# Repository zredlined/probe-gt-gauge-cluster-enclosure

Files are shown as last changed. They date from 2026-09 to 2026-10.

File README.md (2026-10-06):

# Probe GT gauge cluster enclosure

A 3D-printed housing and roll-cage mount for the stock 1993 Ford Probe GT gauge cluster in our 24 Hours of Lemons car.
The dash is gone; the cluster lives in a two-piece charcoal ASA shell with a sun brow, bolted through its own OEM
mounting holes to two small printed feet and two bosses in the roof, and the shell hangs off the dash crossbar and the
two steering-support tubes on four split clamps. Designed from a 3D scan of the cluster and of the cage.

| | | |
|---|---|---|
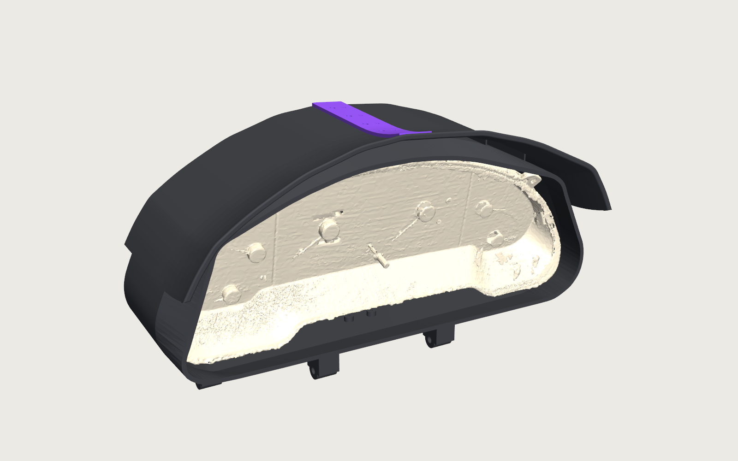
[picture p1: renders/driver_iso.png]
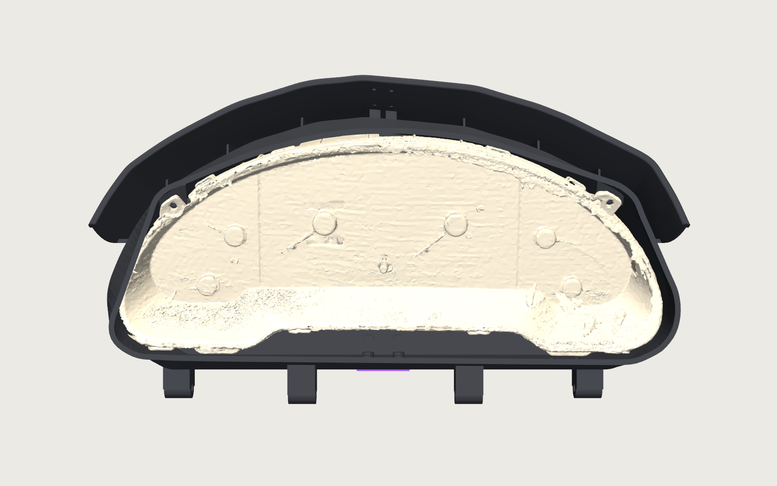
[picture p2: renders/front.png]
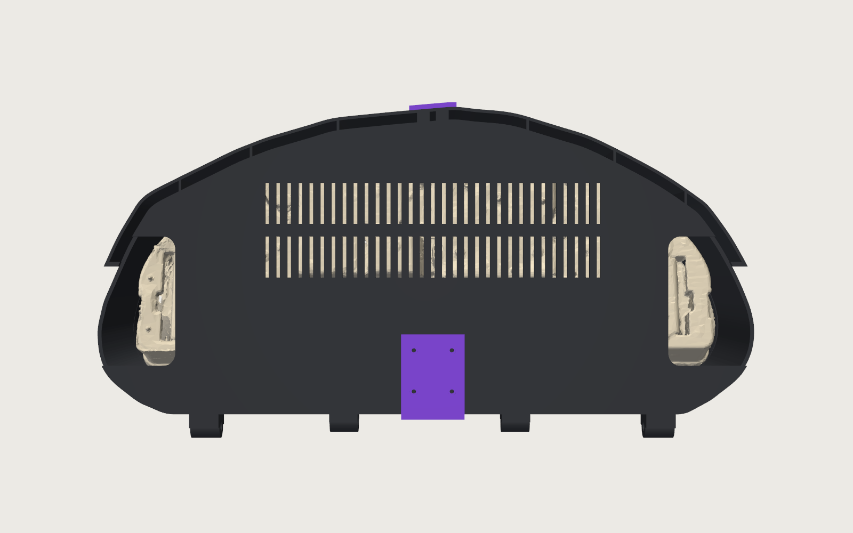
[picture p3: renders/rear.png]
|  |  |  |
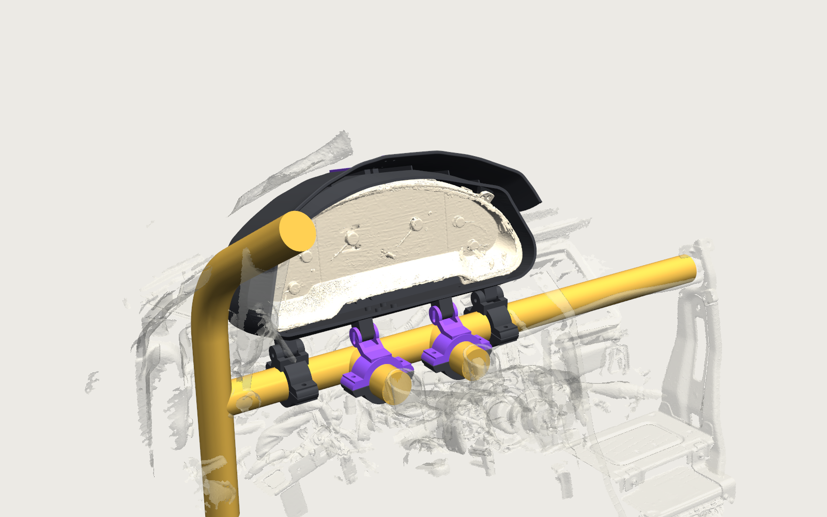
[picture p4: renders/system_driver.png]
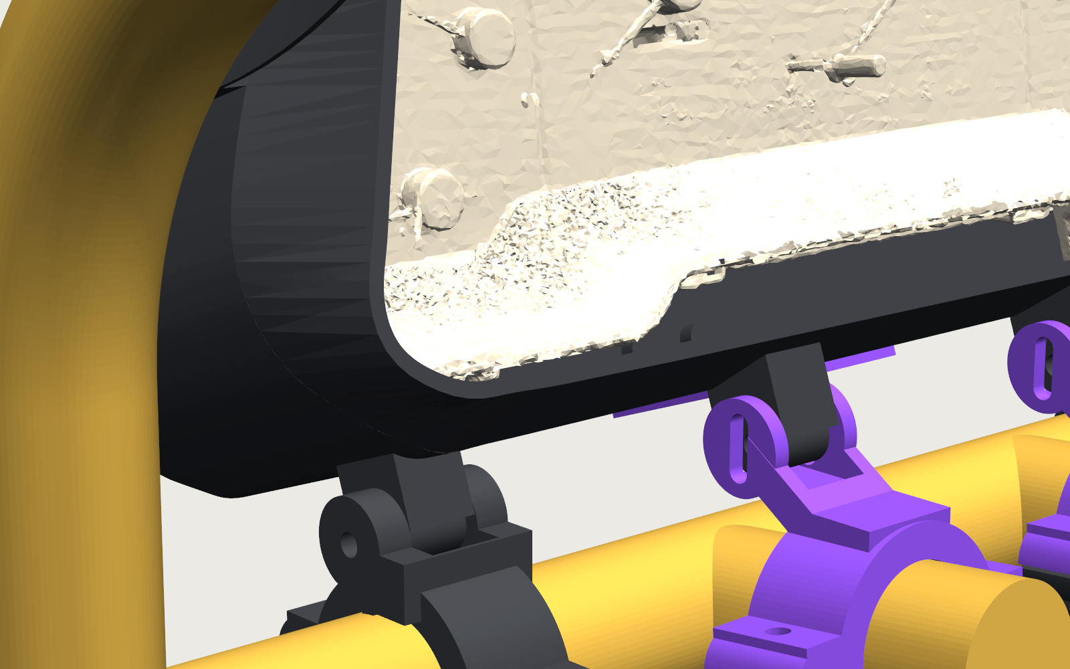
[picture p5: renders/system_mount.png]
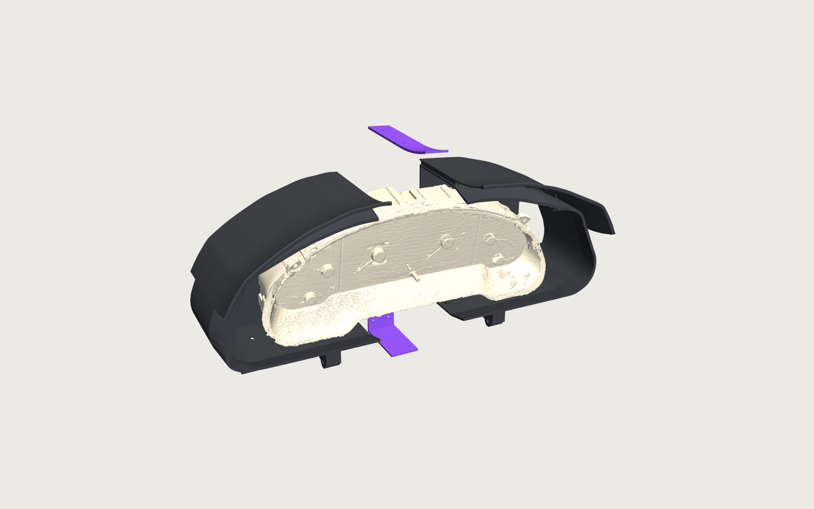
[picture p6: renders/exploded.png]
|  |  |  |

## Print

All files in [`stl/`](stl/) are already oriented for the bed (Bambu P1S, 256 mm). ASA, 0.2 mm layers, 4 walls. The shells
take about 11 hours each; every other part is under 1.5 hours.

| Part | File | Qty | Colour | g | Infill | Supports |
|---|---|---|---|---|---|---|
| Shell L | [shell_L.stl](stl/shell_L.stl) | 1 | charcoal | 396 | 30 % gyroid | tree, only under the two knuckles; brim |
| Shell R | [shell_R.stl](stl/shell_R.stl) | 1 | charcoal | 379 | 30 % gyroid | same |
| Spine bar | [spine_bar.stl](stl/spine_bar.stl) | 1 | purple | 18 | 100 % | small support under the brow tip |
| Keel bar | [keel_bar.stl](stl/keel_bar.stl) | 1 | purple | 16 | 100 % | none |
| Foot L, Foot R | [foot_L.stl](stl/foot_L.stl), [foot_R.stl](stl/foot_R.stl) | 1 each | charcoal | 11 | 60 % | none |
| Bar clamp upper, driver and center | [driver](stl/bar_clamp_upper_driver.stl), [center](stl/bar_clamp_upper_center.stl) | 1 each | charcoal | 41 | 60 % | none |
| Bar clamp lower, driver and center | [driver](stl/bar_clamp_lower_driver.stl), [center](stl/bar_clamp_lower_center.stl) | 1 each | charcoal | 34 | 60 % | none |
| Arm clamp upper, driver and center | [driver](stl/arm_clamp_upper_driver.stl), [center](stl/arm_clamp_upper_center.stl) | 1 each | purple | 44 | 60 % | small support under the strut |
| Arm clamp lower, driver and center | [driver](stl/arm_clamp_lower_driver.stl), [center](stl/arm_clamp_lower_center.stl) | 1 each | charcoal | 34 | 60 % | none |

About 1.2 kg total. Looking at the gauges, L parts go on the right-hand side (the lug plate with round holes) and R
parts on the left (the plate with the slotted hole); every bracket is marked with 1 dot for L, 2 for R. `stl/test/` holds
optional fit aids: ear-boss coupons and ±3° foot variants.

Polymaker ASA on the P1S: nozzle 255 (260 first layer), bed 100 then 95, part fan 15 %, aux fan off, door closed, chamber
preheated, dry the spool first.

## Hardware

Nuts are plain M4 (7.0 AF, 3.2 thick) unless marked nyloc. No heat-set inserts.

| Item | Qty | Where |
|---|---|---|
| M4 x 16 + nut + washer (9 mm OD max) | 4 | lug plates to the feet |
| M4 x 20 + nut + washer | 2 | ear tabs to the roof bosses, from the front through the notch in the lens |
| M4 x 10 + nut | 4 | shell to feet, from below |
| M2.5 x 8 | 18 | spine bar (6) and keel bar (8) self-tapped into printed pilots, brow (4) with M2.5 nuts and washers |
| M6 x 55 + nyloc + 2 washers | 4 | pivot and lock pins through the clamp clevises |
| M6 x 40 + nyloc + washer | 8 | the four split clamps |

Shopping list: 10 M4 nuts, 6 M4 washers, 4 M2.5 nuts and washers, 12 M6 nylocs, 16 M6 washers, plus the bolts above.

## Assembly

1. Press M4 nuts into the hex pockets on the back of each foot slab and into the rear slots of each foot pad.
2. Cluster face down. Foot L behind the face-right lug plate, Foot R behind the face-left plate. Four M4 x 16 from the front.
3. Shell L on its outer side. Drop an M4 nut into the ear-boss channel (it opens upward in this position). Lower the
   cluster with its feet in from the split plane: pads on the bottom wall over the slots, ear tab against the boss.
4. Nut into Shell R's boss channel, then close Shell R over the cluster.
5. Two M4 x 20 from the front through the lens notches into the ear bosses. Four M4 x 10 from below into the feet; slide
   the cluster on the slots until the lens sits about 3 mm behind the nose rim, then tighten.
6. Spine bar: six M2.5 into the roof pilots, four through the brow with nuts. Keel bar: eight M2.5. Hand driver, stop at seat.
7. Ribbon cables in through the rear-corner ports, thumb locks outboard.
8. In the car: bar clamps loose at 107 and 417 mm from the driver-upright weld, clevises up; arm clamps loose about 55 mm
   forward along each steering-support tube, struts up and leaning back.
9. Drop the pivot knuckles into the bar-clamp clevises and the lock knuckles into the arm-clamp slots; four M6 x 55,
   heads outboard. Sit in the seat, set the pitch, tighten pivots, locks, arm clamps, bar clamps. On the bar clamps put
   the bolt heads underneath and the nylocs on top: the cowl-side nuts sit 33 mm under the shell, enough for an open-end
   wrench but not a ratchet.

To remove the cluster: four M6, lift off, two M4 from the front, four M4 from below, bars off, halves apart.

## Design

- The cluster is held only through its OEM holes: four M4 into nuts captured in the feet, two M4 into nuts in bosses
  moulded into the roof. Nothing is glued or drilled.
- The shell's front is a nose lofted to the scanned outline of the bezel rim with 2.5 mm clearance; the roof is a double
  skin over a ventilated air gap that continues as a 70 mm brow. The back is closed with two rows of vents and a port at
  each corner for the ribbon plugs.
- Four identical M6 knuckles on the bottom wall: two pivots directly above the crossbar, two pitch locks 33 mm forward
  above the steering-support tubes, locked on slots.
- Every fastener is driven from outside or on the bench. The generator checks driver reach for all 52 fasteners and
  samples every part against every other part and the cage; the current state is in
  [renders/inspection_sheet.png](renders/inspection_sheet.png).

CAD: Onshape document [937c54b34f0ccb974f37f949](https://cad.onshape.com/documents/937c54b34f0ccb974f37f949) (assembly ids
in `cad/output/onshape_ids.json`). Engineering details: [docs/engineering-notes.md](docs/engineering-notes.md).

## Regenerate

Everything is generated from constants in `cad/generate.py` (shell, feet; scan frame) and `cad/mount.py` (placement,
clamps; car frame). `cad/build.sh` runs the pipeline: geometry, placement, fastener and interference checks, bed-oriented
STLs into `stl/`, renders into `renders/`. `cad/push.py` uploads the FeatureScript to Onshape and rebuilds both
assemblies (about 30 API requests). Environment, once:

```bash
uv venv cad/.venv && uv pip install --python cad/.venv/bin/python cadquery trimesh shapely scipy ezdxf pyvista requests rtree networkx
```

```
cad/         generator, checks, print prep, renders, Onshape push; cad/output holds the generated FeatureScript
stl/         printable files (bed-oriented); stl/test for fit aids
renders/
reference/   cluster_scan (mesh, silhouettes, hole CSV) and cage_scan (fitted tubes, surroundings)
docs/        engineering notes
```

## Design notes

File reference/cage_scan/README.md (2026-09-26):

# Probe cage and dash reference — revision 2

Start with **ONSHAPE_AGENT_HANDOFF.md**. Import **cage_and_dash_reference_mm.stl** in **millimeters**. For separate cage/context visibility, use **cage_primary_tubes_mm.stl** plus **dash_surroundings_mm.stl** instead. All car-reference meshes share coordinates.

The fitted cage is the 1.75-inch (44.45 mm) dash crossbar, driver front upright/bend, and **both tubes reaching toward the steering column**. The arms are also available separately as `cage_steering_support_tubes_mm.stl`; see `steering_support_detail_reference.png`. Their terminal fittings remain scanned surfaces. Gray context preserves the scanned switch, steering hardware and surrounding dash/cowl. The gold color in the PLY and previews is assigned for identification; this scan contains no usable color.

The user's intent is to retain the gauge cluster near its OEM position behind the steering wheel, lift it above the position in the photo, and mount the enclosure at multiple separated front-cage points. Driver eye position remains adjustable.

This is an incomplete spatial reference, not a printable combined solid or a finished mount. Wheel, cluster and full windshield opening are absent from the car scan. The separate earlier cluster reference is in its own coordinates and has not been placed in the car.

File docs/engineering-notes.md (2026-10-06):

# Engineering notes

The non-obvious facts you need to change the design without re-learning them on the printer.

## Frames

- **Scan frame** (enclosure, feet, `cad/generate.py`): X across the cluster, **Y down in the car**, Z toward the driver.
  Scan +X is the driver's left. Part names L / R follow the scan: **L is the face-right side** of the cluster (round-hole
  lug plate, scan holes B2 B3 T1), **R is the face-left side** (slotted lug hole, B5 B6 T2). Every bracket carries dots:
  1 = L, 2 = R.
- **Car frame** (mount, `cad/mount.py`): X along the dash crossbar driver to passenger, Y toward the cowl, Z up, origin on
  the crossbar axis at the driver upright. Scan to car is `car = (X_C - x, -z, -y)` then a 20 deg pitch about X; the
  front-bottom edge of the shell lands `FACE_Y` behind the bar and `EDGE_LIFT` above it.

## What the scan got wrong (calipers, 2026-09-27 to 10-02)

- Mounting holes are all 5.3 mm (B6 is a 5.3 x 8.8 slot); the scan said 5.3 to 6.8. Hole pair spacing 19.7, not 20.2.
- The CSV hole centres lie on the tabs' rear faces. Lug plates 4.8 thick, ear tabs 7.0 thick, 19.5 wide, 10 tall, hole
  5 below the tip; the lens is notched around each tab. Each lug plate has a rib on its outer edge 6 to 7 mm outboard of
  the outer hole.
- The scanner did not see the clear lens: it stands 11 mm proud of the scanned rim and 5 mm proud of the black frame.
- The cluster is 2 to 3 mm deeper than the scan at the rear.
- The bezel shroud tapers toward the face (scanned top edge y -81.6 at the back, -70 at the rim). An opening drawn to the
  widest outline leaves 17 to 29 mm of air; the nose is lofted to the hull of scan vertices with z >= 36 instead.
- Ribbon plugs are 51 and 59.8 x 9.6 mm with a 4 mm thumb lock outboard.

## Design decisions, and why

- **Feet and ear bosses, not a cradle.** v0.4 held the cluster by shape and foam; the solid bosses had no line of sight
  and no fasteners. The cluster now bolts through its own holes: four M4 into nuts captured in two printed feet, two M4
  from the front into nuts in bosses moulded into the roof.
- **No heat-set inserts.** Angled inserts wander when melted in. Nuts sit in printed channels; the only small screws
  (bars) self-tap into 2.4 mm pilots, the value coupon-tested on the race logger. Repair: drill to 3.4, press an insert.
- **Everything is driven from outside or on the bench.** `cad/fastener_check.py` sweeps an 8 mm driver from every head
  at the stage where it is driven and reports the free length with everything fitted; it also samples every clamp against
  the shell and the shell against the cage tubes. Both checks exist because printed parts found the problems first.
- **Knuckles**: four identical, M6, pin 16 mm below the wall so 12 to 13 mm clevises clear it; clamp rings are notched
  under the knuckles. Lock knuckles sit 33 mm forward of the pivots for a usable pitch-lock lever arm.
- **Known tight spot**: the rear-bottom corner of Shell R passes 2.9 mm from the scanned dash remnant on the driver
  side (car x 76, y 90, z 50). If it touches in the car, `FACE_Y` -38 -> -35 moves the whole enclosure 3 mm toward the
  driver; everything else re-derives.
- **Placement**: gauge face about 16 mm behind the crossbar's driver-side surface, front-bottom edge 50 mm above the bar
  top, face leaning back 20 deg, centred on the steering column. Eye point and windshield base in `mount.py` are guesses.

## Generator

One geometry description drives two backends: CadQuery (dense polylines, local STLs, mesh checks) and FeatureScript (fit
splines, the Onshape custom features). Verified FeatureScript behaviours: intersections via SUBTRACT_COMPLEMENT, sheared
prisms via opLoft, halves via opSplitPart, 0.3 mm overlaps instead of coincident spline faces, boolean tools are consumed
(build a fresh tool per boolean), `coordSystem()` needs exactly perpendicular axes (re-orthogonalise in FS), an empty tool
list is an error. The feature carries step tracking: on failure it creates a body named `FAILED step N: ...`.

Onshape document `937c54b34f0ccb974f37f949`: Part Studio 1 (enclosure + feet), "Mount (car frame)" Part Studio, Feature
Studio "Cluster enclosure FeatureScript" (both features), "Enclosure assembly" and "Full system (car frame)" assemblies
(ids in `cad/output/onshape_ids.json`, rebuilt by `push.py`). A push is about 29 API requests.

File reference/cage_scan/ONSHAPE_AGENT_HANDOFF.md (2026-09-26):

# Probe race-car cage and dash — Onshape handoff

Revision 2, September 26, 2026: added both 1.75-inch tubes projecting toward the steering column as fitted reference geometry. Supersedes the initial package. All model coordinates are **millimeters**.

## User's intended outcome

Design a stable, serviceable cage-mounted support for the gauge-cluster enclosure the user is building. Keep the cluster approximately in its OEM driver-side location behind the steering wheel, lifted above where it rests in the supplied photo. Use multiple separated attachment points on the front cage to limit rotation and vibration. The user also confirmed that the two tubes reaching toward the steering column are 1.75 inches and should be considered as candidate anchors. The user has not specified lift, pitch, or final mount dimensions. Keep the driver's eye position adjustable.

This package supplies the surrounding reference geometry and fitted cage, not a completed mount. Start with the user's current enclosure CAD when it becomes available. The previous gauge-cluster mesh describes the cluster itself; it is not the new enclosure.

## Start here

1. Import `cage_and_dash_reference_mm.stl` with units set to **millimeters** for a combined context reference.
2. For separate selection/visibility, instead import `cage_primary_tubes_mm.stl` and `dash_surroundings_mm.stl`. These share the same origin and orientation. Do not independently center or align them. Avoid displaying these together with the combined STL, which duplicates their surfaces.
3. Use `onshape_reference_geometry.json` and `cage_centerlines_mm.csv` to reconstruct native CAD cage envelopes if useful. The crossbar is a straight 44.45 mm diameter cylinder; the driver upright is a straight–circular-bend–straight sweep of the same diameter. The two short steering-support arms are straight cylinders of the same diameter, each with its own fitted axis.
4. Bring in the user's enclosure and establish its placement separately. The car scan and earlier cluster scan have **not** been registered to each other. Do not import the earlier cluster at identity and assume the placement is meaningful.
5. Add adjustable eye, steering-wheel, cluster-lift and pitch references, then resolve visibility, access and mounting geometry together.

`car_reference_photo.png` provides installed-wheel and loose-cluster context. It is not a calibrated camera view or a source of precise dimensions. The hood is raised in the photograph.

## Files and purpose

| File | Purpose |
|---|---|
| `cage_and_dash_reference_mm.stl` | Combined nominal cage and surrounding scanned geometry; easiest starting reference |
| `cage_primary_tubes_mm.stl` | Fitted main dash crossbar, driver front upright/bend, and both steering-support arms |
| `cage_dash_crossbar_mm.stl`, `cage_driver_upright_mm.stl` | Individual tube envelopes |
| `cage_steering_support_tubes_mm.stl` | Both fitted 44.45 mm arms projecting toward the steering column |
| `driver_side_steering_support_mm.stl`, `center_side_steering_support_mm.stl` | Individual fitted arm envelopes |
| `steering_arm_fit_report.json` | Arm axes, model bounds, fit residuals and limitations |
| `steering_support_detail_reference.png` | Close-up showing the newly fitted arms and scanned end fittings |
| `dash_surroundings_mm.stl` | Scanned context with most duplicate main-tube surfaces removed |
| `dash_context_mm.stl` | Complete reconstructed scan before replacing primary cage surfaces; use to compare fits |
| `master_switch_region_scan_mm.stl` | Cropped switch, plate and nearby surfaces, already in car coordinates |
| `steering_supports_region_scan_mm.stl` | Cropped scanned support area; includes nearby surfaces |
| `cage_and_dash_reference_color.ply` | Gold cage/gray context for CloudCompare or other color-capable viewers |
| `onshape_reference_geometry.json` | Exact reference coordinates, bend definition and unset placement parameters |
| `cage_centerlines_mm.csv` | Ordered tube centerline samples, with nominal outside diameter |
| `native_scan_to_cad_mm.txt` | Homogeneous 4×4 native-scan-to-delivered-frame transform |
| `cage_fit_report.json`, `mesh_quality_report.json`, `export_validation.json` | Fit residuals, scan comparison and export checks |
| `driver_view_reference.png`, `driver_oblique_reference.png`, `top_view_reference.png`, `cage_only_reference.png` | Orientation and coverage previews |
| `unplaced_cluster_reference/` | Prior cluster mesh and eight-hole estimates, in their own separate coordinate system |

STL has no reliable color or units metadata. Select millimeters explicitly. The PLY's gold/gray colors are assigned for identification, not recovered scan texture. No source colors were available in this car scan.

## Coordinate system and cage geometry

Origin: main crossbar centerline at its closest approach to the driver-side upright axis, near the left junction.

- **+X:** along the crossbar from the driver side toward the center/passenger side.
- **+Y:** forward toward the lower cowl/windshield.
- **+Z:** upward, derived from the driver upright and orthogonalized to the crossbar. This is an approximate vehicle frame, not a measured gravity datum.

| Reference | Delivered geometry, mm |
|---|---|
| Nominal cage outside diameter | **44.45** (user-specified 1.75 inches) |
| Crossbar centerline | (0, 0, 0) to (782.252, 0, 0) |
| Driver upright bottom center | (-0.356, -1.061, -166.519) |
| Driver upright top center | (36.380, -182.935, 287.977) |
| Upright bend centerline radius | 134.578, fitted approximation |
| Bend turn angle | 56.918 degrees |
| Bend start | (0.206, -1.061, 94.360) |
| Bend end | (12.238, -61.034, 207.097) |
| Approximate steering axis point near hub | (266.139, -317.480, 57.955) |
| Steering axis direction toward driver | (-0.006766, -0.911536, 0.411164) |

The steering axis was estimated from cylindrical column surfaces; the point near the hub is an approximate axial endpoint, **not a measured wheel mounting face**. The steering column is not a cage member.

The crossbar was extended a short distance through the obscured left weld junction to the upright. All tube end caps are artificial model truncations. They do not represent physical tube ends. Tube models are solid outside envelopes; no wall thickness is inferred. The four members overlap at their joints and are not boolean-unioned. Surrounding scan surfaces are open and incomplete; the combined STL is a spatial reference, not a watertight printable object.

For an analytic upright path, use the JSON bend center C, radius R, start tangent u and direction h:

`P(theta) = C + R * (-cos(theta) * h + sin(theta) * u)`

for theta from 0 to the reported turn angle. Connect the reported bottom to bend start, and bend end to top. Use a circular 44.45 mm section. Exact data are in the JSON; do not use the rounded table for reconstruction.

## Coverage and uncertainty

Source project: `/Users/redlined/Documents/EXStar Hub/probe fuel dash monster` (the matching project on disk; the user called it “probe fuel dash monitor”). Source point data: `Project_1/frame0/cloud.bin`. Project metadata identifies an Einstar Rockit scan, marker alignment and 0.5 mm point spacing. The source contains 2,928,868 points. It was reduced to 438,812 prepared points using 1.25 mm voxel sampling and isolated-point filtering. The mesh was reconstructed, trimmed near the observed surface, and reduced to 220,000 triangles before fitted tubes were substituted.

The fitted primary tubes are the main dash crossbar, driver-side front upright/bend, and both 44.45 mm arms reaching toward the steering column. The user explicitly identified those arms as candidate mounting locations. Their terminal fittings, welds, brackets, steering hardware, switch, lower cowl and center-dash supports remain scanned context. Geometry alone does not establish the available clamping space or load capacity. Passenger upright, door bars, roof bars and full windshield boundary are not reconstructed from this scan. Do not extend the model into a complete cage without new measurements.

At nominal 44.45 mm OD, radial RMS residuals on selected straight tube surfaces are approximately 0.38 mm for the crossbar, 0.31 mm for the lower upright, and 0.33 mm for the upper upright. The inferred circular bend has approximately 0.45 mm surface RMS residual. Free-diameter checks gave about 44.70, 44.80 and 44.57 mm respectively. These are fit statistics on partial surfaces, **not guarantees of physical accuracy or clamp clearance**.

The scan-to-mesh check for the original context has approximately 0.32 mm 95th-percentile distance; the combined nominal-cage/context reference is approximately 0.50 mm. This measures reproduction of the prepared scan, not scanner calibration, unobserved surfaces or absolute accuracy. All four individual tube-envelope exports were read back and checked as watertight, orientable and non-self-intersecting after welding duplicate STL vertices. This does not make the combined scene watertight. Larger local errors remain around edges, thin parts and gaps. Confirm actual painted OD and chosen clamp locations before fixing a production fit.

## Newly included steering-support arms

These are the two short gold tubes visible in the supplied photo, one on each side of the steering column. They project rearward from the dash crossbar toward the driver (negative Y), with a slight rise. They are separate from the central steering column itself.

| Member | Axis at crossbar plane Y=0, mm | Axis at model boundary Y=-100, mm |
|---|---|---|
| Driver-side arm | (199.715, 0, -0.864) | (205.404, -100, 7.629) |
| Center-side arm | (323.854, 0, -0.068) | (325.098, -100, 7.220) |

Both use the user-confirmed **44.45 mm OD**. The clean straight scan surfaces between roughly Y=-24 and Y=-92 were used for fitting, excluding the terminal fittings. They give radial RMS residuals of approximately 0.10 and 0.09 mm respectively; free-diameter checks give 44.60 and 44.58 mm. These fit statistics are not physical accuracy or clamp-fit guarantees. Exact axes and selected point counts are in `steering_arm_fit_report.json`.

The fitted envelopes extend into the crossbar junction and end at Y=-100 where the terminal fittings begin. These are model transition boundaries, not the physical overall lengths of the complete supports. Open terminal fittings and weld details remain in the scan mesh; no bore diameter, wall thickness or fabricated end feature is inferred. Do not use the capped envelopes as hole geometry or fill in the missing interiors in the production design.

A preliminary search region for a clamp is Y=-80 to -35 on each straight arm. This is a region to inspect, not 45 mm of guaranteed unobstructed clamp width. Compare against the complete scan, brackets, welds, wiring and the real car. Retain the existing steering assembly and its clearance when evaluating the arms.

## Placement, sight lines and access

Keep the enclosure in the original gauge-binnacle region behind the wheel. Use the steering axis and photo as initial qualitative references; neither fixes the cluster's final transform. Lift and tilt the enclosure as parameters. Do not default to relocating it over the center stack.

The wheel and cluster are absent from this car scan. Add a wheel reference using measured rim OD, rim thickness, dish/offset and its mounting datum before assessing obstruction. The photo alone does not establish these dimensions. Keep eye position and an optional eye box adjustable, as requested. Do not present a chosen camera render as a verified driver's view.

With a candidate placement, check rays from the adjustable eye positions to the gauge face/corners against the wheel, enclosure lip and cage. Check forward visibility using the real windshield opening and seated-driver position when available; the scanned lower cowl alone cannot establish the complete road view. Also check hands at the rim, steering controls and wheel removal/installation space.

The left master power switch must remain visible and reachable. The supplied crop contains its observed plate/handle pose and nearby surfaces; its bounding box is **not** an operational clearance envelope. Allow for the full lever throw, hand access and rear wiring after confirming them on the car. The scan and supplied photo may capture different handle positions.

## Mount concept to develop next

Evaluate a stiff enclosure support using separated attachments on the front crossbar and the two newly modeled steering-support arms. The arms offer attachment positions offset toward the driver from the crossbar axis, potentially helping resist enclosure pitch without a long brace toward the left upright. Compare a crossbar-plus-arms layout against a simpler pair of arm clamps with sufficient rotational restraint. Place clamps around existing welds, end fittings, brackets and wiring. Keep a driver-upright brace as an alternative only where switch access and space permit. A brace off the crossbar axis provides another way to resist enclosure pitch; exact anchors and geometry are not fixed by this package.

Use the enclosure's structural mounting features to carry loads, with multiple enclosure attachment points. Do not use the PCB as the structural connection. Include service access and cable routing. Split clamps are a starting concept that preserves the existing cage; no cage drilling or welding has been designed here. Mount stiffness, hardware sizing and any vibration isolation must be resolved with the enclosure mass and available space. Multiple attachments alone do not establish vibration performance.

Before completing the full mount, make a small clamp-fit sample and a simple placement mockup to confirm fit, desired lift, switch access and actual seated visibility. No final bracket thickness, hardware torque, load capacity or vibration performance has been established.

## Related cluster reference

The package's `unplaced_cluster_reference/` contains copies of the earlier `cluster_onshape_reference_mm.stl`, `mounting_hole_estimates_mm.csv` and `README_Onshape.md`. The user confirmed the labeled T1–T2 and B1–B6 are the eight intended mounting holes. Preserve the uncertainty and measurement guidance in that earlier README. These files are independent cluster coordinates and require a placement transform into this car frame; the new enclosure geometry is still needed for mount design.

Original folder: `/Users/redlined/Documents/Playground/gauge_cluster_mesh_2026-09-25/`.

## Suggested prompt for the next agent

“Read ONSHAPE_AGENT_HANDOFF.md and import the cage/dash references in millimeters. Use my current gauge-cluster enclosure CAD. Keep it behind the steering wheel near the OEM location, lifted above the loose position in the photo. Consider the two modeled 1.75-inch steering-support arms as well as the crossbar. Develop a mount from multiple separated front-cage attachments that controls rotation and vibration while preserving power-switch access, steering clearance and serviceability. Leave the driver's eye position adjustable. The cluster/enclosure is not yet registered to the car; establish and expose that placement rather than assuming the imports align. Show candidate placement and attachment geometry before finalizing fit-dependent dimensions.”

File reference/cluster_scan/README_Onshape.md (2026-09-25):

# Probe gauge cluster — enclosure reference for Onshape

## Start here

Import **cluster_onshape_reference_mm.stl** into Onshape, selecting **millimeters**. This is a scan reference mesh, not the enclosure and not a watertight printable part. It has 149,999 triangles and is approximately 404.5 × 173.6 × 105.3 mm in its supplied coordinate frame. Those are scan-envelope dimensions, not nominal factory dimensions.

The original EXStar projects and the earlier merged point cloud were not modified. CloudCompare performed 0.5 mm spatial subsampling and an independent cloud-to-mesh distance check. Open3D performed depth-10 Poisson reconstruction with four threads. Surface farther than 1.25 mm from the prepared input samples was trimmed, very small disconnected components were removed, and a simplified reference was exported. No extra surface smoothing was applied. The installed CloudCompare Poisson plugin has no command-line entry point, so reconstruction itself ran outside CloudCompare.

## Deliverables

- `cluster_onshape_reference_mm.stl`: light mesh to import into Onshape, **millimeters**; STL cannot carry colors.
- `cluster_onshape_reference_color.ply`: same light mesh with captured colors for CloudCompare.
- `cluster_detailed_color.ply`: 1.77-million-triangle color mesh for detailed inspection.
- `cluster_observed_surface_color.ply`: ball-pivot mesh for inspecting scan-supported edges and openings; less complete than the Poisson mesh and not a manufactured solid.
- `case_outline_xy_mm.dxf`: the projected outer silhouette only, simplified by 0.2 mm from the light mesh's XY projection. This includes protrusions and mounting tabs; it is not a section at a particular depth.
- `case_outline_and_mounts_xy_mm.dxf`: the same silhouette plus projected opening fits, center crosses and labels. These are scan-derived references, not nominal hole sizes or a drill template.
- `mounting_hole_estimates_mm.csv`: eight fitted 3D opening centers, local face normals, apparent rim dimensions and fit residuals.
- `mounting_holes_identification.png`: the eight holes confirmed by the user.
- `mounting_hole_fits.png`: original rear-scan samples and fitted rims.
- `reference_cloud_cad_mm_color.ply`: prepared input cloud in the same coordinates as the meshes and guides.
- `cloudcompare_mesh_deviation.ply`: CloudCompare's independent unsigned distance check, saved as a scalar field on the cloud.

PLY colors come from nearest captured samples. Reconstruction does not recreate uncaptured marker imagery; EXStar's marker symbols remain separate app annotations.

## Eight mounting references

All eight estimates were fitted to the **original rear scan only**, not to the merged mesh. Their relative positions therefore do not depend on the front-to-back registration. Local planar faces were isolated and rim boundary samples fitted with circles or capsule approximations. B6 is clearly elongated; B2's fit is only mildly elongated. Do not choose screws or nominal drill sizes from these apparent rim dimensions: chamfers, incomplete bore sampling and point spacing bias the observed opening size.

Coordinates are in the exact same frame as the STL and DXF. X runs across the case. In the labeled rear view, Y increases downward. Z is depth, with the rear viewed from negative Z. The DXF is an XY projection at Z=0; the actual mounting faces are at different Z values. Use the 3D values and local face orientation when creating mounting surfaces. Face normals describe the scanned faces, not a measured internal bore axis.

| Hole | X mm | Y mm | Z mm | Rim fit RMS mm |
|---|---:|---:|---:|---:|
| T1 | -167.25 | -26.59 | 31.86 | 0.25 |
| T2 | 155.52 | -23.87 | 27.81 | 0.25 |
| B1 | -131.73 | 75.47 | -6.04 | 0.11 |
| B2 | -152.73 | 84.13 | -7.47 | 0.15 |
| B3 | -132.89 | 84.01 | -8.23 | 0.19 |
| B4 | 121.96 | 74.32 | -8.44 | 0.31 |
| B5 | 117.60 | 82.88 | -10.43 | 0.13 |
| B6 | 137.93 | 82.74 | -10.35 | 0.18 |

Numeric precision in the CSV is for reproducibility and does not imply that level of physical accuracy. The source scan spacing is 0.5 mm. Rim fit RMS values of about 0.11–0.31 mm describe agreement to sampled rim points, not true-location accuracy. Independent physical measurements remain necessary for bolt fit.

## Verification and limits

- Against the earlier 1.2-million-point cropped cloud, median distance to the light mesh is 0.058 mm, 95th percentile 0.467 mm, and about 99.0% is within 1 mm. This measures reconstruction fidelity, not scanner accuracy. The maximum is 36.8 mm; some source samples have no nearby retained surface, so coverage is not universal.
- In the eight original rear-scan rim neighborhoods, the 95th-percentile point-to-mesh distances range from 0.16 to 0.28 mm. The actual opening-center references are fitted to raw scan data independently of those mesh facets.
- Original scans were aligned with 20 shared markers, 0.50 mm marker RMS mismatch. This affects the merged enclosure envelope, even though the eight-hole layout uses only the rear scan.
- The earlier ground removal used a 6 mm plane clearance and a bounding crop. Full untrimmed aligned copies remain in `../gauge_cluster_alignment_2026-09-25/` for recovering any contact-adjacent region. Hole fitting used those full copies and isolated the relevant faces.
- Poisson reconstruction may interpolate gaps and soften small openings. Use the fitted center references and physical measurements for mounts, not triangulated hole edges as nominal geometry.
- The STL is intentionally open where scan support was insufficient. Do not run automatic hole filling just to make the reference printable.

## Suggested Onshape workflow

1. Import the STL in millimeters and keep it as a reference in a Part Studio. Verify that its width is approximately 405 mm to catch an import-unit error. Avoid converting every mesh triangle into a CAD face.
2. Import the DXF, create an empty XY sketch and use **Insert DXF or DWG**, in millimeters. Preserve its coordinates relative to the mesh. The outline is useful for a first enclosure profile; it is not a constant-depth mating edge. Add your intended clearance to new enclosure geometry rather than rescaling the scan.
3. Create a dimensioned mounting layout from the eight centers, using the CSV for depth. Measure actual hole diameters/slots, mounting-face heights and a few spans before fixing the CAD dimensions. Model bosses against the structural mounting tabs rather than against the PCB or connector bodies.
4. First make small test pieces that engage the left and right three-hole groups. Confirm screw fit, spacing and seating. Check the two upper mounting points before committing to a full shell. A useful cross-check is the top T1–T2 center distance: the scan estimate is 322.80 mm; the lower B2–B3 span is 19.86 mm, B5–B6 is 20.33 mm, and B3–B5 is 250.51 mm. These are 3D straight-line center distances, not measurements along a curved surface.
5. Build a separate rear shell with working clearance around the scanned body and electronics. A few millimeters is a reasonable initial packaging allowance, to adjust after a fit check; leave additional deliberate room for connector plugs, wire bends and tool access. Add a removable cover, mounting bosses and cable openings as normal parametric CAD features.
6. Design the race-car brackets around the verified enclosure mounting structure. The scan alone does not establish material choice, vibration strength or final bracket loads.

Official references:
- Onshape mesh reference/mixed modeling: https://cad.onshape.com/help/Content/PartStudio/mixed_modeling.htm
- STL/OBJ import units: https://cad.onshape.com/help/Content/uploadfiles.htm
- DXF insertion into a sketch: https://cad.onshape.com/help/Content/Sketch/insert_dwg_or_dxf.htm
- CloudCompare Poisson reconstruction: https://cloudcompare.org/doc/wiki/index.php/Poisson_Surface_Reconstruction_%28plugin%29

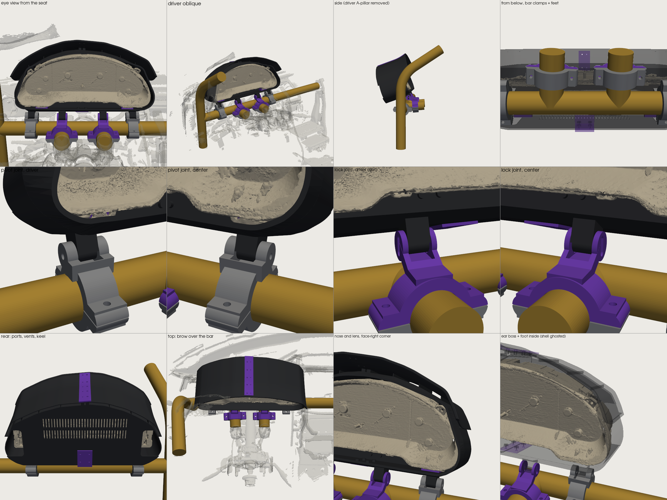
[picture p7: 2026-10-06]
renders/inspection_sheet.png

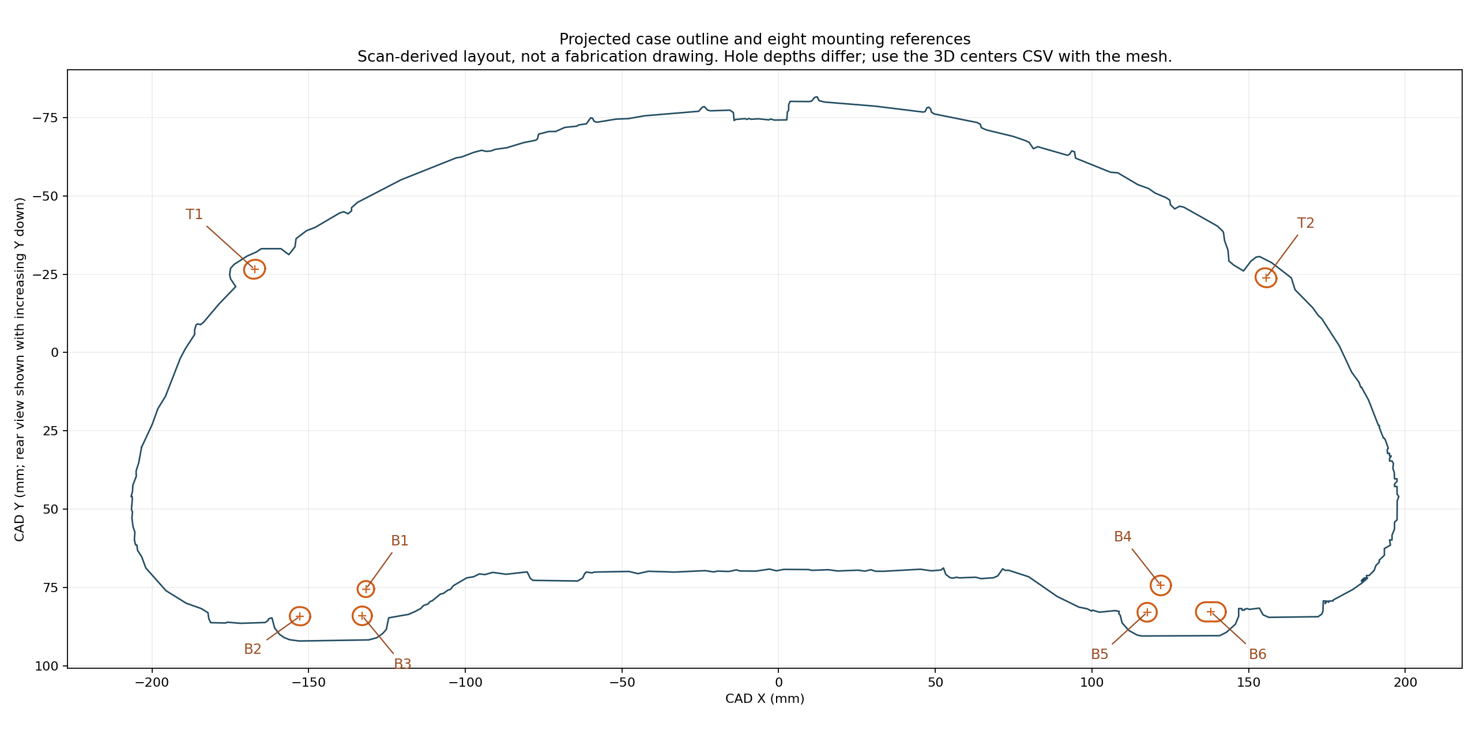
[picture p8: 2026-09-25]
reference/cluster_scan/case_outline_and_mounts.png

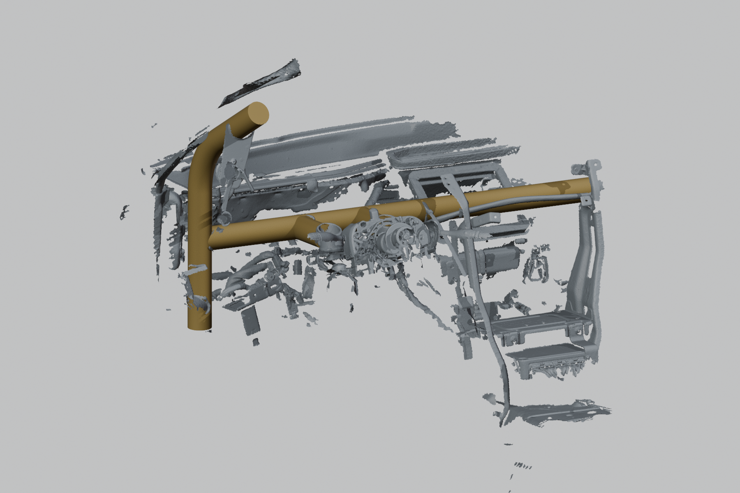
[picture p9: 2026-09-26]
reference/cage_scan/driver_oblique_reference.png

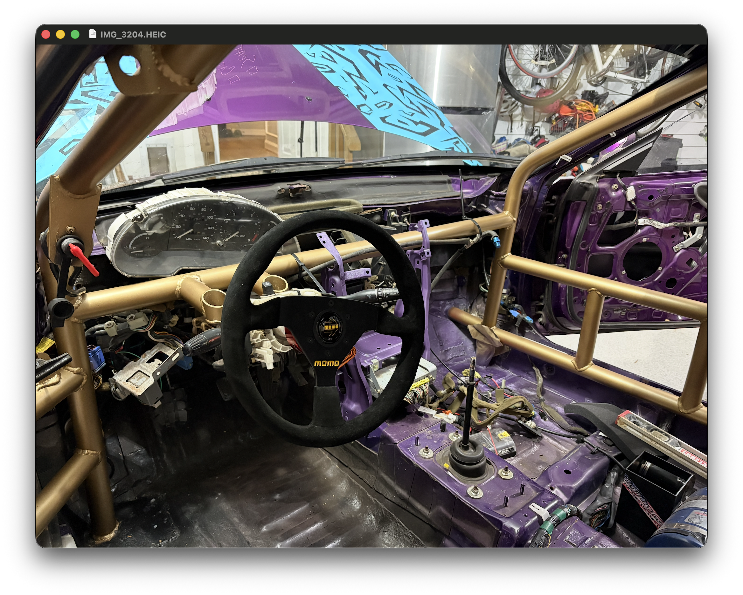
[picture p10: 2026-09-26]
reference/cage_scan/car_reference_photo.png

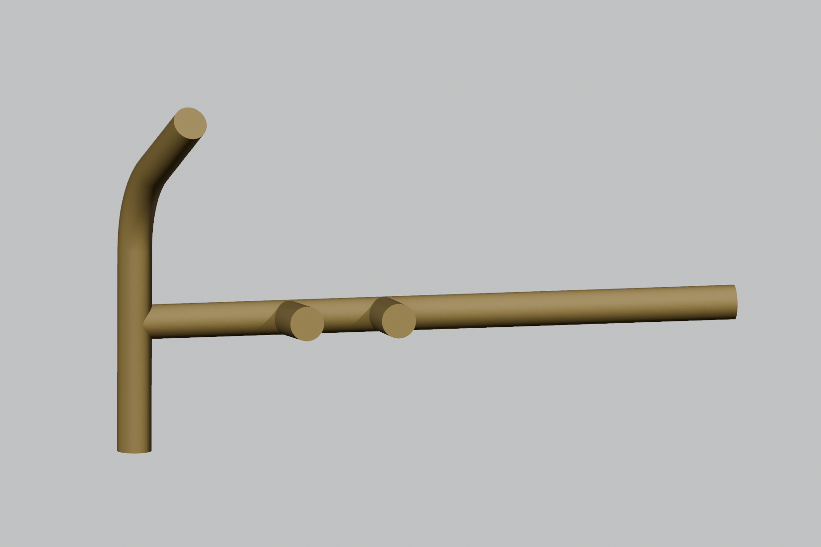
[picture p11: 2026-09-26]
reference/cage_scan/cage_only_reference.png

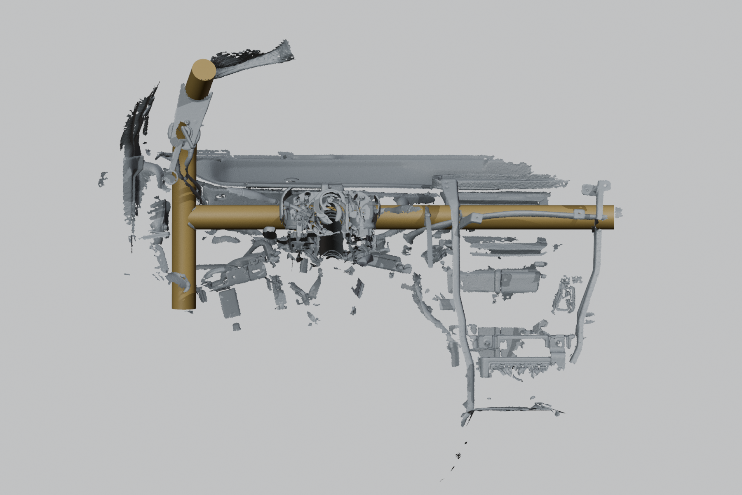
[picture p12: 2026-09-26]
reference/cage_scan/driver_view_reference.png

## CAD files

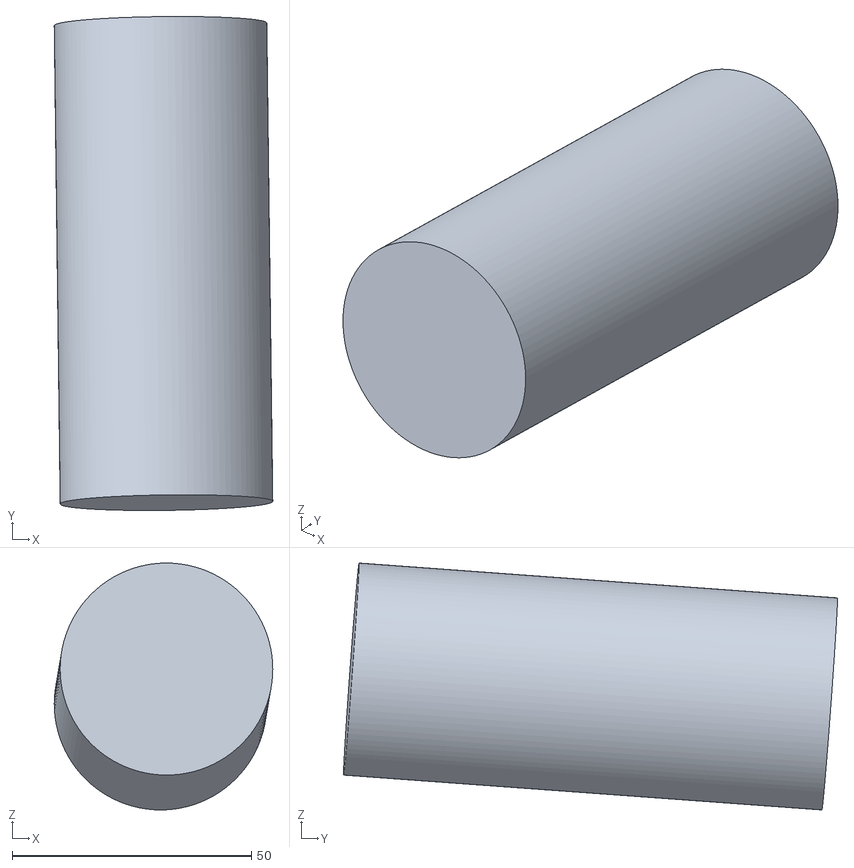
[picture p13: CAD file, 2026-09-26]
reference/cage_scan/center_side_steering_support_mm.stl
45.7 x 103.3 x 51.6

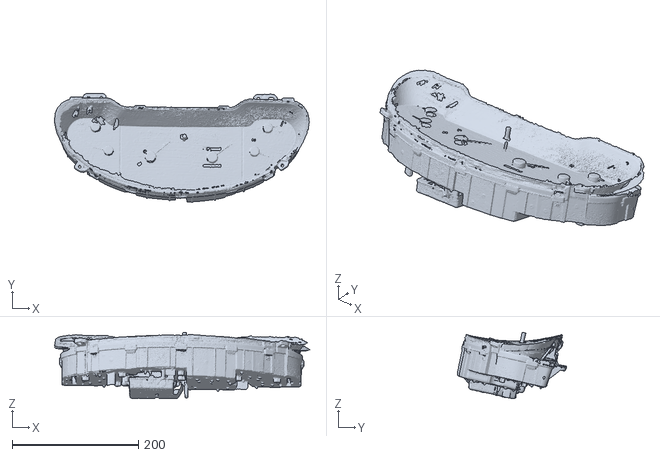
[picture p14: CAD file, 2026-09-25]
reference/cage_scan/unplaced_cluster_reference/cluster_onshape_reference_mm.stl
404.5 x 173.6 x 105.3

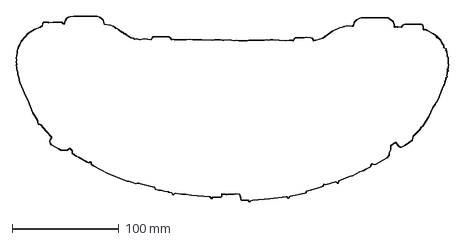
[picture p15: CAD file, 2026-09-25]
reference/cluster_scan/case_outline_xy_mm.dxf
404.6 x 173.6 mm

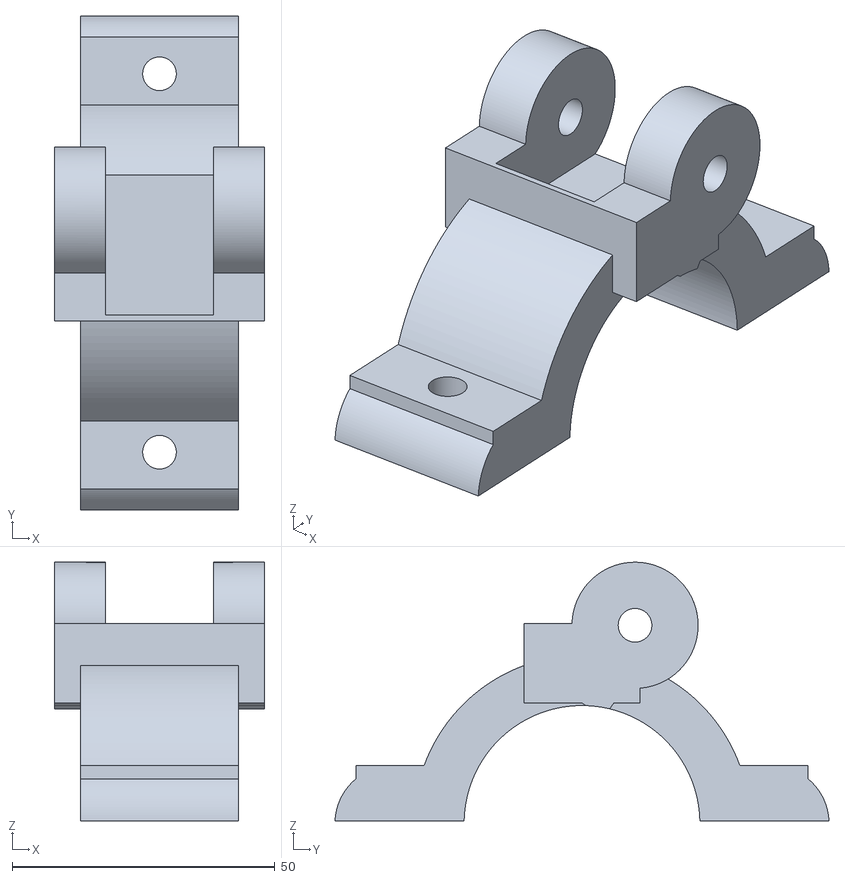
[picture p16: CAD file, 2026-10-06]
stl/bar_clamp_upper_center.stl
40.0 x 94.0 x 49.2

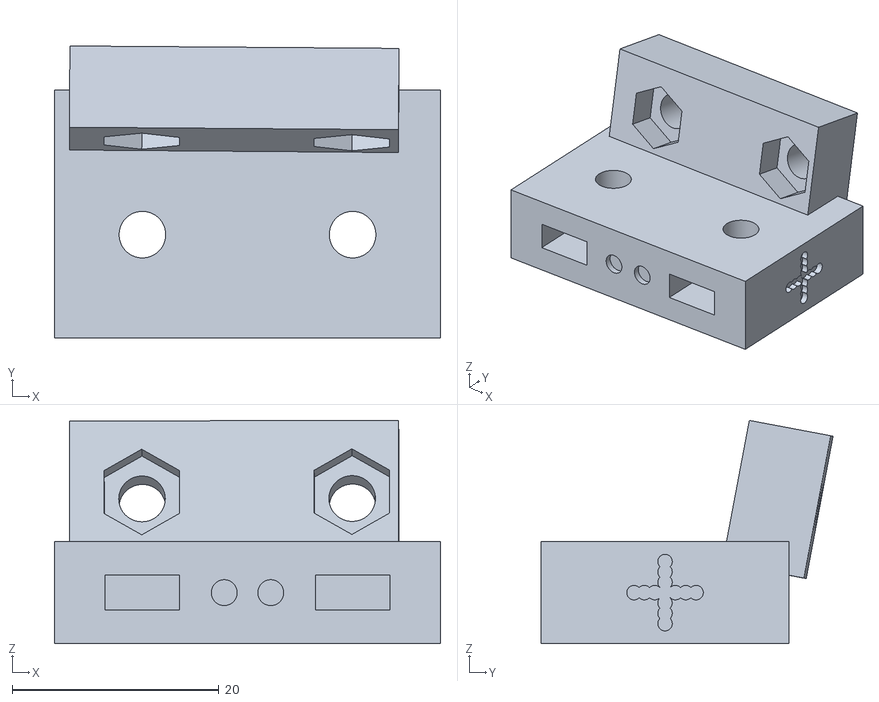
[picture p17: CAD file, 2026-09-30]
stl/test/foot_R_tilt+3.stl
37.3 x 28.2 x 21.6

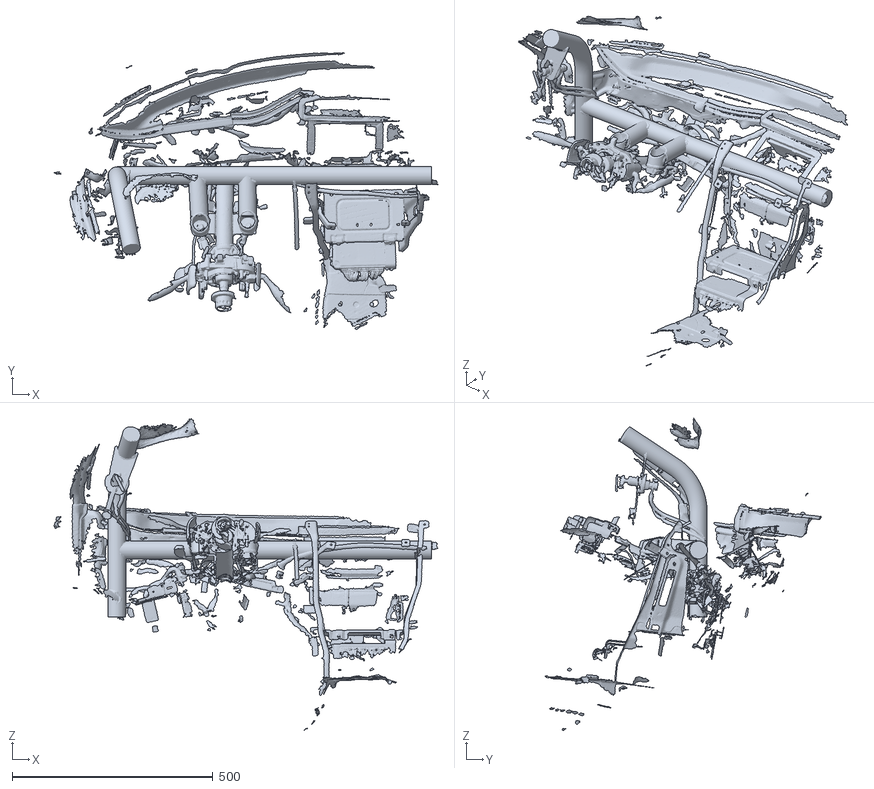
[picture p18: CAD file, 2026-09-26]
reference/cage_scan/cage_and_dash_reference_mm.stl
955.7 x 689.1 x 776.9

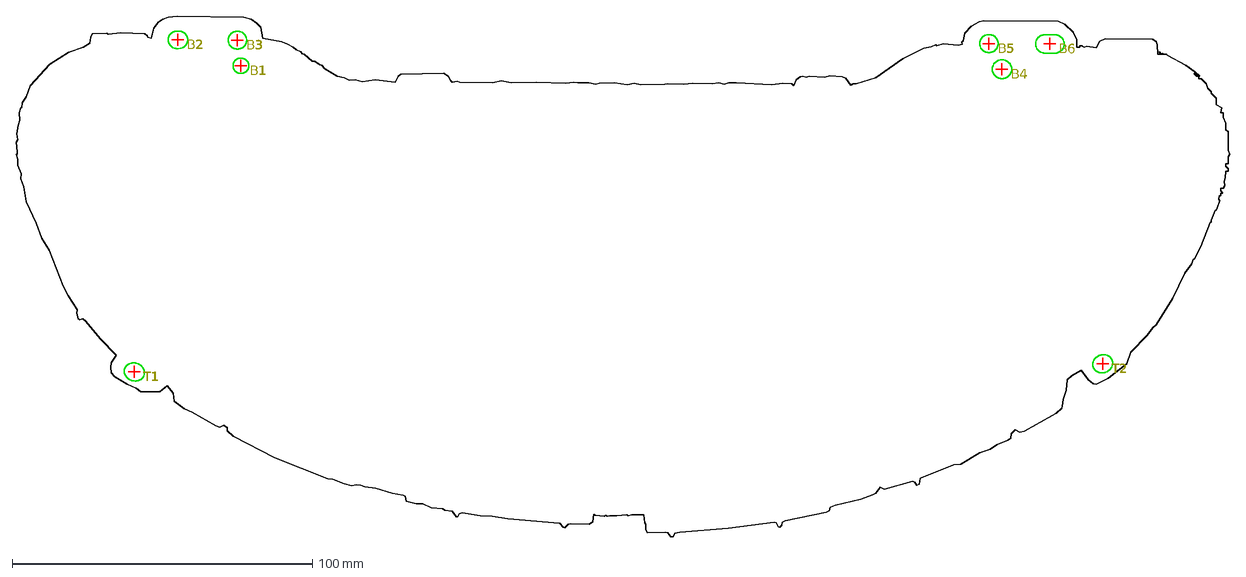
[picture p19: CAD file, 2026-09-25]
reference/cluster_scan/case_outline_and_mounts_xy_mm.dxf
T1
T2
B1
B2
B3
B4
B5
B6

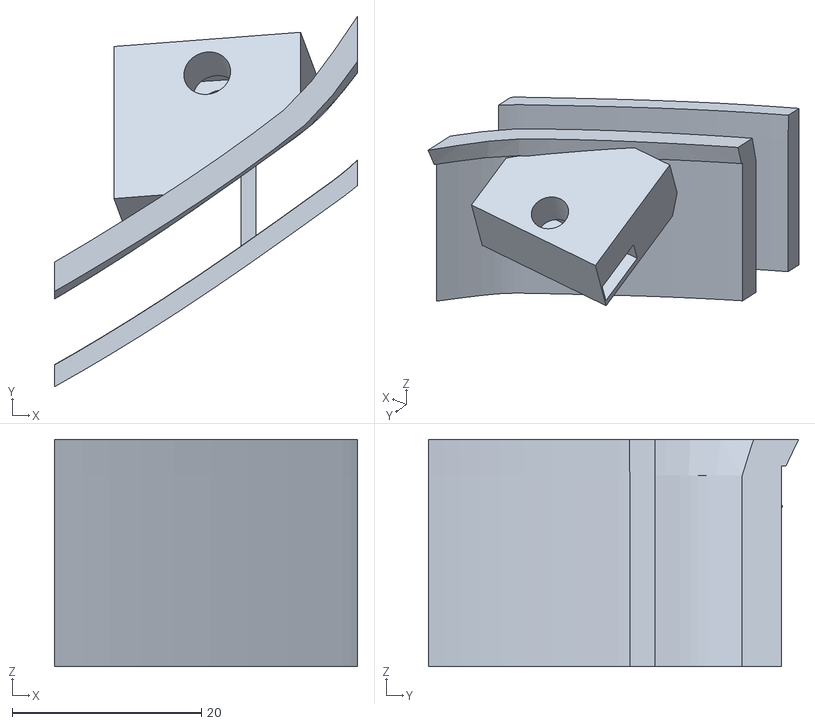
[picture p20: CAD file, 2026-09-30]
stl/test/ear_coupon_R.stl
32.0 x 39.1 x 24.0

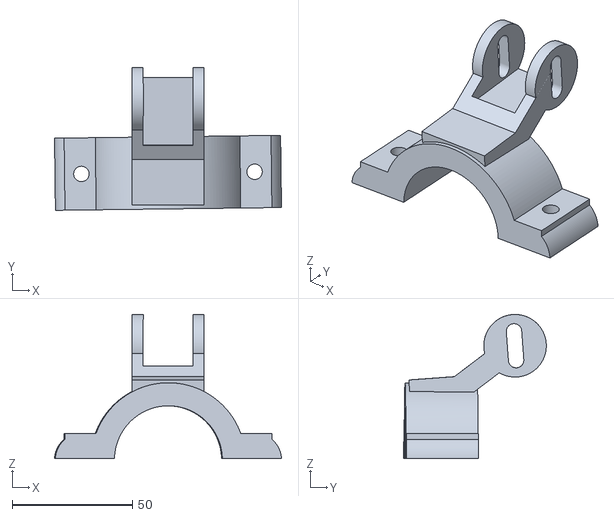
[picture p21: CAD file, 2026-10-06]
stl/arm_clamp_upper_center.stl
94.3 x 59.3 x 59.9

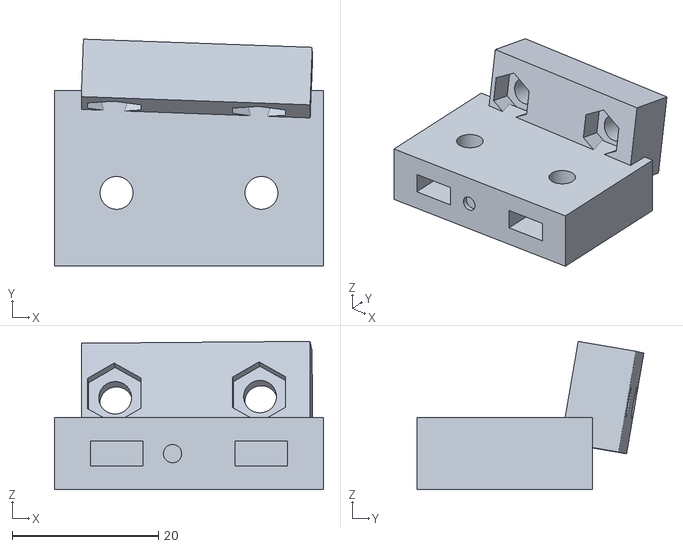
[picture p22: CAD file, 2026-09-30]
stl/test/foot_L_tilt+3.stl
36.8 x 31.1 x 20.3

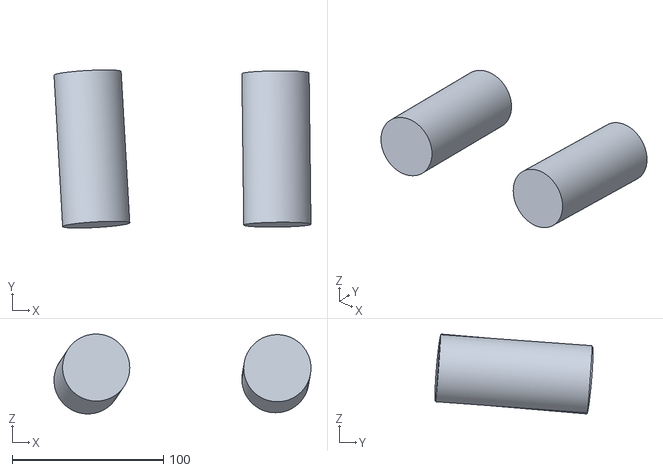
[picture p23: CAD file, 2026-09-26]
reference/cage_scan/cage_steering_support_tubes_mm.stl
169.8 x 104.5 x 52.8

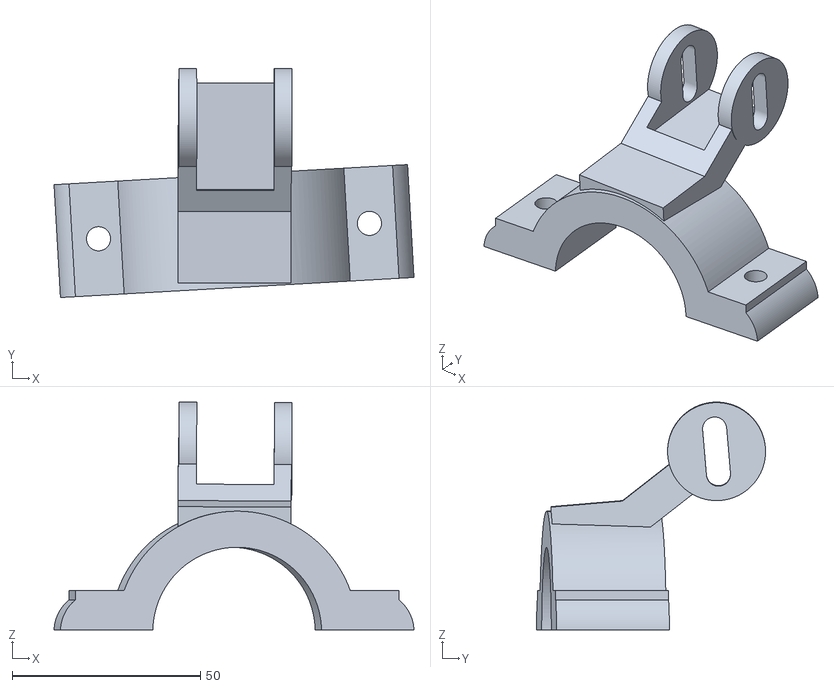
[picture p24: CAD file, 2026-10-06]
stl/arm_clamp_upper_driver.stl
95.5 x 60.8 x 60.5

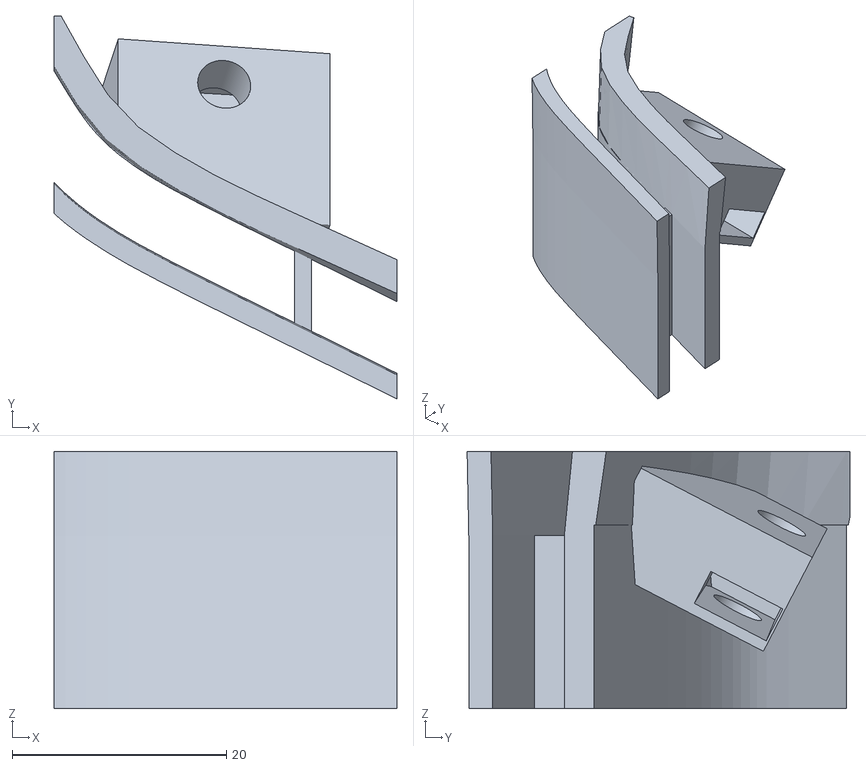
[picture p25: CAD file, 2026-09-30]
stl/test/ear_coupon_L.stl
32.0 x 35.7 x 24.0

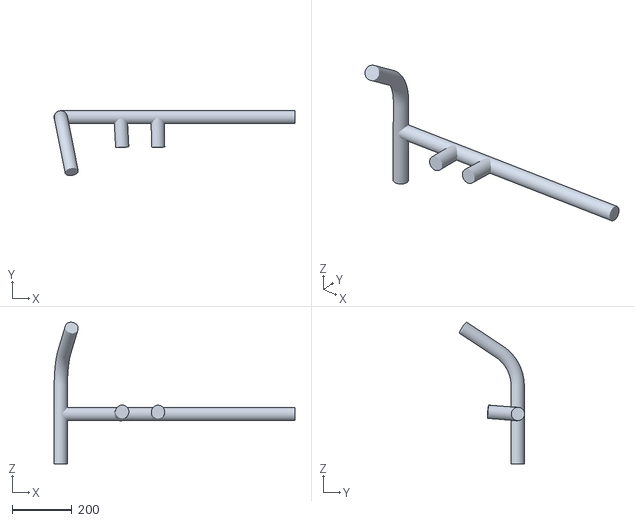
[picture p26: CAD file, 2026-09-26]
reference/cage_scan/cage_primary_tubes_mm.stl
804.8 x 217.8 x 473.2

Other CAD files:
stl/bar_clamp_upper_driver.stl
reference/cage_scan/cage_and_dash_reference_color.ply
reference/cluster_scan/cluster_onshape_reference_color.ply
reference/cage_scan/cage_dash_crossbar_mm.stl
reference/cage_scan/cage_driver_upright_mm.stl
reference/cage_scan/dash_context_mm.stl
reference/cage_scan/dash_surroundings_mm.stl
reference/cage_scan/driver_side_steering_support_mm.stl
reference/cage_scan/master_switch_region_scan_mm.stl
reference/cage_scan/steering_supports_region_scan_mm.stl
stl/arm_clamp_lower_center.stl
stl/arm_clamp_lower_driver.stl
stl/bar_clamp_lower_center.stl
stl/bar_clamp_lower_driver.stl
stl/foot_L.stl
stl/foot_R.stl
stl/keel_bar.stl
stl/shell_L.stl
stl/shell_R.stl
stl/spine_bar.stl
stl/support_pieces.3mf
stl/test/foot_L_tilt-3.stl
stl/test/foot_R_tilt-3.stl
stl/test/test_coupon.stl

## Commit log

2026-09-25 Probe GT gauge cluster enclosure v0.3: scan-based cradle shell, arched brow, ribbon ports, Onshape generator
    Two-half ASA shell around the OEM cluster (no fasteners into it), double-skin roof with
    ventilated air gap continuing into a curled brow, closed back with two ribbon-cable ports and
    vents, spine and keel bars in 4OGS purple, M6 cage-mount pads. Generator emits CadQuery STLs,
    renders and the Onshape FeatureScript from one set of constants; scan reference package and
    build guide included.
    [case_outline_and_mounts_xy_mm.dxf, case_outline_xy_mm.dxf, cluster_onshape_reference_color.ply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]
2026-09-26 Cage mount v0.1 and enclosure v0.4
    Enclosure: two M8 pivot knuckles under the lug blocks and an M6 stay boss on the driver-side wall replace the rear pads.
    Mount (car frame): two split crossbar clamps with raked blade struts and clevises, upright clamp with ear, slotted pitch
    stay, column support stubs fitted from the scan. Placement transform scan->car with lift/pitch parameters and checks
    (road sightline, gauge visibility over the rim, clearances). Dash cage reference package, full-system renders, build
    guide with mount hardware and fitting steps; push.py now maintains the mount Part Studio and both Onshape assemblies.
    [cage_and_dash_reference_color.ply, cage_and_dash_reference_mm.stl, cage_centerlines_mm.csv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]
2026-09-26 Mount v0.2: face leans back 20 deg, lift 100, arms raked 100 mm, knuckles under lug blocks
    Pitch sign corrected (face now looks up at the driver like the OEM binnacle). Eye and windshield-base assumptions raised
    from the photo; enclosure lifted so the brow sits at that sightline; cluster shifted 20 mm toward the centre to clear the
    swept-back A-pillar bar and the master switch. Full-system assembly transform now covers the cluster surface bodies.
    [mount_bar_clamp_lower_l.stl, mount_bar_clamp_lower_r.stl, mount_bar_clamp_upper_l.stl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]
2026-09-26 Mount v0.3: four-point clamp mount on crossbar and steering-support arms; enclosure v0.4 knuckles
    Placement per user direction: gauge face 16 mm behind the crossbar on the driver side, body over the bar toward the
    windshield, front-bottom edge 50 mm above the bar, face leaning back 20 deg. Two split crossbar clamps carry clevises for
    the enclosure's M8 pivot knuckles (now above the bar, overlapping the lug ledge blocks); two split arm clamps carry short
    struts with slotted M6 lock clevises for new lock knuckles at the enclosure's front-bottom edge. Side-bar stay removed.
    Cage reference rev 2 with both arms fitted; build guide rewritten with mount parts, hardware, print orientation, how the
    k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
    [cage_and_dash_reference_color.ply, cage_and_dash_reference_mm.stl, cage_centerlines_mm.csv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]
2026-09-26 push.py: mount feature parameter ids for v0.3 (buildBar, buildArms)
2026-09-27 Print-ready STLs and plate plan (print_prep.py); start-here section in the build guide
    [print_arm_clamp_lower_center.stl, print_arm_clamp_lower_driver.stl, print_arm_clamp_upper_center.stl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]
2026-09-27 Build guide: M2.5 sizes carried over from the logger coupon; clamp half is the first print
2026-09-27 Fit-test sections cut from the shells (front rings, cradle corners, ear corners); build guide leads with them
    [fit_cradle_L.stl, fit_cradle_R.stl, fit_ear_L.stl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]
2026-09-27 Build guide: Shell L is the first print; fit sections are the fallback
2026-09-28 v0.5 chassis: two bolted lug feet replace the cradle; build guide and README updated with the test-print measurements
    The first Shell L print showed the shape-and-foam cradle was unusable (solid
    stop pads, lug plates unreachable). The cluster now bolts through its OEM
    5.3 mm holes (B2 B3 / B5 B6, M4 + captured nuts) to two small printed feet
    whose pads reach the shell bottom wall and carry M2.5 inserts for shell
    screws driven from outside, above the knuckles. No ear feet: the scan shows
    the ear tabs boxed in by housing top, cavity roof and bezel; v0.5 shell will
    slot the ear tips instead.
    generate.py: tab_frame()/place() (rigid local-frame placement, both
    backends), build_feet(), buildFeet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
    [foot_lug_l.stl, foot_lug_r.stl, print_foot_lug_L.stl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]
2026-09-28 v0.5 cover shell + fastener access check
    Shell: cradle features removed (no ledges, fins, stop pads, ear pads); front
    and lips 11.5 mm forward for the clear lens the scanner missed; rear wall
    3 mm back; 20 mm roof slots capture the ear tips; ribbon ports 4 mm taller
    each way for the 60 mm plug; four counterbored M2.5 holes through the
    bottom wall over the feet. Keel bar bottom leg stops at z 12 so the M6 lock
    nuts have wrench room. Mount regenerated for the new front edge.
    fastener_check.py: sweeps an 8 mm driver from every head along its axis at
    the assembly stage where it is driven (feet / close / car) against the
    parts present then, requires 60 mm (driver) or 30 mm (nut) of reach, and
    re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
    [fit_cradle_L.stl, fit_cradle_R.stl, fit_ear_L.stl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]
2026-09-28 Ear slots sized from the measured tabs (19.5 x 7, 10 tall): 21.5 x 11 mm
    [fit_ear_L.stl, fit_ear_R.stl, print_fit_ear_L.stl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]
2026-09-28 Ear blocks (M4 into captured nut behind each ear tab, two M2.5 inserts up to the roof), roof screw tubes through the double skin, slotted foot-screw holes, +-3 deg lug-foot variants; hardware table w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
    [ear_block_l.stl, ear_block_r.stl, fit_cradle_L.stl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]
2026-09-30 Ear block R was built upside down (local up axis flipped for the +x ear): tab_frame now forces local +y up; ID marks (1 dot L, 2 dots R, -/+ bars on tilt variants); ear block renders
    [ear_block_l.stl, ear_block_r.stl, foot_lug_l.stl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]
2026-09-30 v0.6: nose lofted to the scanned bezel rim, ear bosses in the roof with side-entry M4 nut channels, feet with rear-entry M4 nut slots, all-M4 hardware; lock knuckles to z 18; build guide and README r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
    The v0.5 opening followed the widest outline at the back of the bezel
    shroud and left 17-29 mm of air around the face; the shroud tapers, so
    from NOSE_Z0 = 30 the wall now lofts (loft_regions, both backends) to the
    smoothed hull of scan vertices with z >= 36 plus 2.5 mm, with a 4 mm rim.
    Brow and spine bar spring from NOSE_Z0.
    Serviceability: no heat-set inserts at angles. Ear blocks become bosses
    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
    [ear_block_l.stl, ear_block_r.stl, fit_cradle_L.stl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]
2026-09-30 Ear nut channel: flat end clears the nut corners (was a round pocket that stopped the nut 0.5 mm short), 7.2 -> 7.6 taper to the mouth; foot nut slots the same; ear-boss coupons cut from the shells f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
    [ear_coupon_L.stl, ear_coupon_R.stl, fit_cradle_L.stl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]
2026-10-02 Bar clamp uppers: pivot strut started at the tube axis and filled the half-bore (found on the printed parts); strut now starts inside the ring wall and the bore is re-cut after the union on all four 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
    [mount_arm_clamp_upper_center.stl, mount_arm_clamp_upper_driver.stl, mount_bar_clamp_upper_center.stl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]
2026-10-02 v0.7 mount interface: all four knuckles identical M6 (20 x 24 x 24, pin 16 mm below the wall), clevises 12/13 mm that clear the shell, lock knuckles back at z 40 (33 mm lever arm) trimmed by the cavi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
    [mount_arm_clamp_upper_center.stl, mount_arm_clamp_upper_driver.stl, mount_bar_clamp_upper_center.stl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]
2026-10-02 Build guide: v0.7 knuckles and all-M6 mount hardware
2026-10-02 v0.7: bar screws self-tap into 2.4 mm printed pilots (no heat-set inserts anywhere); guide and README updated
    [print_shell_L.stl, print_shell_R.stl, shell_l.stl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]
2026-10-03 Repo simplified: README is the canonical build page (renders, printable files, hardware, assembly); cad/ generator, stl/ bed-oriented prints, renders/, reference/ scans, docs/engineering-notes.md; ge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
    [arm_clamp_lower_center.stl, arm_clamp_lower_driver.stl, arm_clamp_upper_center.stl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]
2026-10-06 Clamp uppers: strut root passes through the full ring wall (base just outside the bore) with a 6 mm shoulder each side; the old tangent root snapped on a friend's print
    [arm_clamp_upper_center.stl, arm_clamp_upper_driver.stl, bar_clamp_upper_center.stl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]
2026-10-06 Clamp uppers: bore re-cut spans the full strut root width (root had dipped into the tube outboard of the ring); fastener check covers the 8 clamp bolts and mount-vs-cage interference (52 fasteners, 0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
    [bar_clamp_upper_center.stl, bar_clamp_upper_driver.stl]
2026-10-06 Verification pass: 12-view inspection sheet, bar-clamp bolt orientation, dash clearance note
2026-10-06 README: print times, side convention in plain words, shopping list, inspection sheet link, environment setup
2026-10-06 push.py --mount-only: re-insert only the mount feature and rebuild the full-system assembly (19 requests instead of 29); Onshape current
2026-10-21 Low-profile cradle: saddle feet (lug slab + forward bar + clamp saddle on the crossbar), face at 24 deg, bar 45 mm behind the face; reuses the printed clamp lowers; checks against cluster, tubes, das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
2026-10-21 Cradle backplate: two lapped halves following the front silhouette (inset 2), ribbon ports, vents, ear ties from the proven ear blocks straight back to corner bumps, flanges under the saddle feet usi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
2026-10-21 Cradle in Onshape: third custom feature (clusterCradle) in the shared Feature Studio, Part Studio 'Cradle (scan frame)', assembly 'Cradle system (car frame)' reusing the cage, surroundings and cluste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
2026-10-21 Cradle v1.1 aesthetics: tapered ear fins, louvres following the arch with a clear logo panel, rounded ribbon ports, purple centre spine over the lap carrying the counterbored lap screws
2026-10-21 Saddle feet: wedge between the forward bar and the ring filled, bar flush with the ring width, bore and split plane re-cut
2026-10-21 Cradle v1.2: plate-to-foot joint turned 90 deg (bosses from the plate to the pad rear faces, M4 x 30 from behind into pad nut pockets), M6 nylocs captured in the saddle flanges, driver grooves for th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
2026-10-21 Skeleton mount (v2.0) and one folder per build option
    Skeleton mount: the cluster hangs between two flat side plates on two crossbar clamps, built from the OPEN28 prototype
    (reference/open28) with every joint replaced by a proven one: mount.split_clamp uppers with M5 bosses and captured nuts,
    M6 nylocs in the flange tops, the lug slab and ear block from the shell version, nut pockets on every cross bolt, a
    saddle extension on the passenger upper where dash hardware leaves no room for a clamp. cad/sidemount.py,
    sidemount_check.py (fastener access at each assembly stage, nut insertion, M6 tips, interference, installation paths),
    render_sidemount.py, onshape_views.py; push.py --sidemount upload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
2026-10-21 Front page: skeleton mount hero render (rear three-quarter, mount in full view)
